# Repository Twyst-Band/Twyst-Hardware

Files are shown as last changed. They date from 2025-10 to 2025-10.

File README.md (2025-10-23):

# Twyst — Intelligent Motion Tracking & Exercise Feedback System

## Overview

Twyst is a wearable motion analysis system that integrates sensor-embedded bandanas with an intuitive mobile application to monitor, evaluate, and improve human movement. Designed for sports, fitness, rehabilitation, and physical therapy, Twyst provides real-time feedback on exercise execution accuracy using advanced motion analysis and AI-based comparison algorithms.

Developed by students from the National College of Computer Science “Grigore Moisil” Brașov, Twyst combines embedded engineering, data science, and mobile app design to create a seamless hardware-software ecosystem that makes motion tracking accessible and engaging.
 
## Objectives

Twyst aims to:
- Provide precise motion analysis using distributed wearable sensors.
- Deliver live, data-driven feedback for form correction and performance improvement.
- Develop a machine-learning framework that learns from professionals and guides beginners.
- Support medical rehabilitation by tracking therapeutic exercises and preventing re-injury.
- Offer a comfortable, modular, and scalable hardware system adaptable to various body types and activities.

Key operational goals include:
- <2° RMS error in orientation estimation.
- 95% exercise recognition accuracy.
- Real-time posture correction feedback.
- 8+ hours battery life and automatic calibration.

## How It Works

The system operates in two main phases:
1.	Training Phase – A professional user performs multiple repetitions of an exercise wearing several Twyst bandanas. The algorithm identifies the most relevant sensors and stores their motion data as a reference.
2.	User Phase – A beginner attaches bandanas to the same body parts and performs the exercise. Twyst compares their movement to the reference model, scoring accuracy and providing corrective suggestions.

Twyst uses sensor fusion (Kalman filters) to combine gyroscope, accelerometer, and magnetometer data. Movement analysis and comparison are based on Principal Component Analysis (PCA) for segmentation and Bézier curve modeling for motion representation, ensuring precise yet efficient feedback.

## Related Work

Twyst draws inspiration from several existing systems:
- SlimeVR: Open-source IMU-based full-body tracker for VR; lacks exercise integration and suffers from drift.
- OptiTrack: High-precision optical tracking used in professional environments; too costly and complex for personal use.
- Oculus Insight: Inside-out tracking with 6DoF accuracy; limited to upper-body movement and headset constraints.

Twyst bridges the gap — delivering OptiTrack-like accuracy with SlimeVR’s affordability and Oculus’ simplicity, optimized for fitness and rehabilitation.

## Software Architecture

Mobile Application
- Built in SwiftUI (iOS), with an Android version in development.
- Features include:
- Exercise browsing and categorization.
- Live activity tracking and performance analytics.
- Gamified UI inspired by Duolingo, featuring progress visualization, rewards, and motivational feedback.
- Mascot: Twy — a friendly athletic fox serving as a motivational guide and branding symbol.

Embedded Software
- Runs on ESP32-C3 using the Arduino framework (C).
- Handles sensor communication (SPI/I²C), data fusion, calibration, and Bluetooth data transfer.
- Implements local Kalman filtering before aggregating data to the main bandana and mobile app for analysis.

## Hardware Design

Bandana Types
- Main Bandana: Acts as the master node; equipped with a touchscreen, pulse oximeter, and temperature sensor.
- Secondary Bandanas: Smaller, lightweight, and communicate with the main unit via UWB and Bluetooth.

## Components

Component	Model / Description
Microcontroller	ESP32-C3
IMU	MPU9250
UWB Module	Ai-Thinker BU03 DW3000
Display	Waveshare Round TFT (GC9A01 driver)
Pulse Oximeter	GY-MAX30100
Temperature Sensor	MF52
Battery	Li-Po with Boost Regulator HW626
Material	PETG 3D-printed enclosures, nylon straps

## Electronics & Prototyping
- Designed using KiCad for PCB schematics.
- 3D-printed casings optimized for comfort and modular assembly.
- Built for durability, skin safety, and easy debugging.

## Business Model

Twyst’s business strategy focuses on:
- Selling hardware kits (bandanas + mobile app).
- Generating secondary revenue from anonymized motion data used in research, medicine, and biomechanics.
- Promoting accessibility and personalization to encourage wide adoption across fitness, rehabilitation, and research markets.

Business Plan
Research Paper

## Research & Algorithms

Twyst’s research focuses on mathematical modeling for accurate motion comparison:
- Sensor Model: Quaternion-based orientation estimation via Kalman filtering.
- Segmentation: PCA identifies repetitions and removes noise.
- Motion Representation: Bézier curves smooth motion data for scalable comparison.
- Evaluation Metrics: Curve distance, amplitude, and phase alignment define feedback precision.

These techniques ensure low drift, real-time responsiveness, and robust cross-user comparison.

## License

This project is currently in research and prototype stage under educational use. Future licensing will be determined upon commercial release.
 presentation)?

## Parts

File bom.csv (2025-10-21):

Designator | Footprint | Quantity | Value | LCSC Part #
C1, C2, C3 | C_0402 | 3 | 10µF
D1, D2 | 0402 | 2 | LED
D3 | Nexperia_CFP3_SOD-123W | 1 | PMEG4020ER
J1 | JST_PH_S2B-PH-K_1x02_P2.00mm_Horizontal | 1 | Conn_01x02_Pin
Q1 | SOT-23 | 1 | BSS84
R1 | R_0402 | 1 | 5.1kΩ
R2 | R_0402 | 1 | 2kΩ
R3, R4 | R_0402 | 2 | 1kΩ
R5 | R_0402 | 1 | 100kΩ
R6, R7 | R_0402 | 2 | 4.7kΩ
SW1 | SW_SPDT_PCM12 | 1 | SW_SPDT
U1 | TDFN-8_L3.0-W2.0-P0.50-BL-EP1.6 | 1 | MCP73831-2ACI/MC | C150772
U2 | SOT-23-5_L2.9-W1.6-P0.95-LS2.8-BR | 1 | AP2112K-3.3TRG1_C23380830 | C23380830
U4 | LGA-14_L3.0-W2.5-P0.50-TL | 1 | ICM-45686 | C22459454
U5 | WLCSP-12_L1.6-W1.6_BMM150 | 1 | BMM150 | C171681
U6 | MODULE_ESP32-C3_SUPERMINI_TH | 1 | ESP32-C3_SUPERMINI_TH
USBC1 | USB-C_SMD-TYPE-C-31-M-12_1 | 1 | TYPE-C-31-M-12 | C165948
`

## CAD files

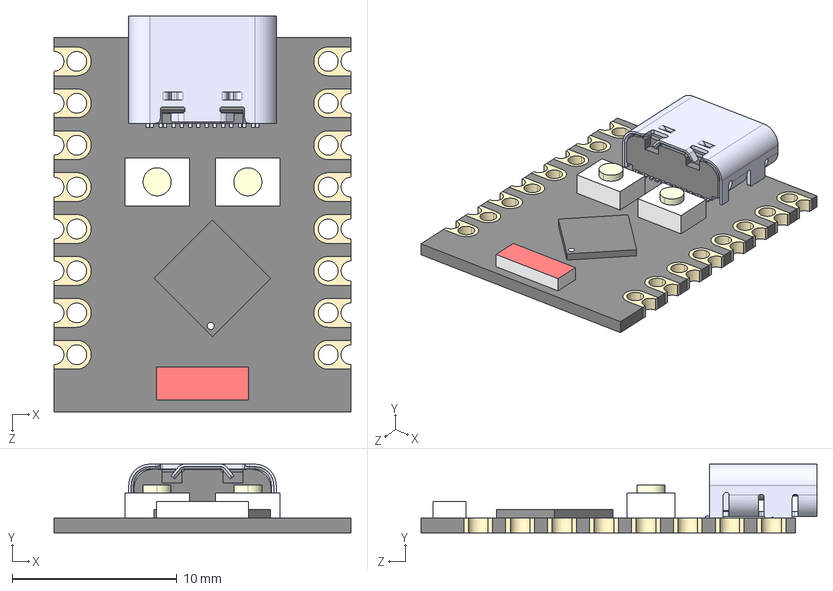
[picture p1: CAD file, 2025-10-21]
Electrical/ESP32-C3 SuperMini TH/ESP32-C3_SUPERMINI_TH.step
18.0 x 4.16 x 24.0 mm
Board c3mini
USB C
components (other)^ESP32-C3 SuperMini

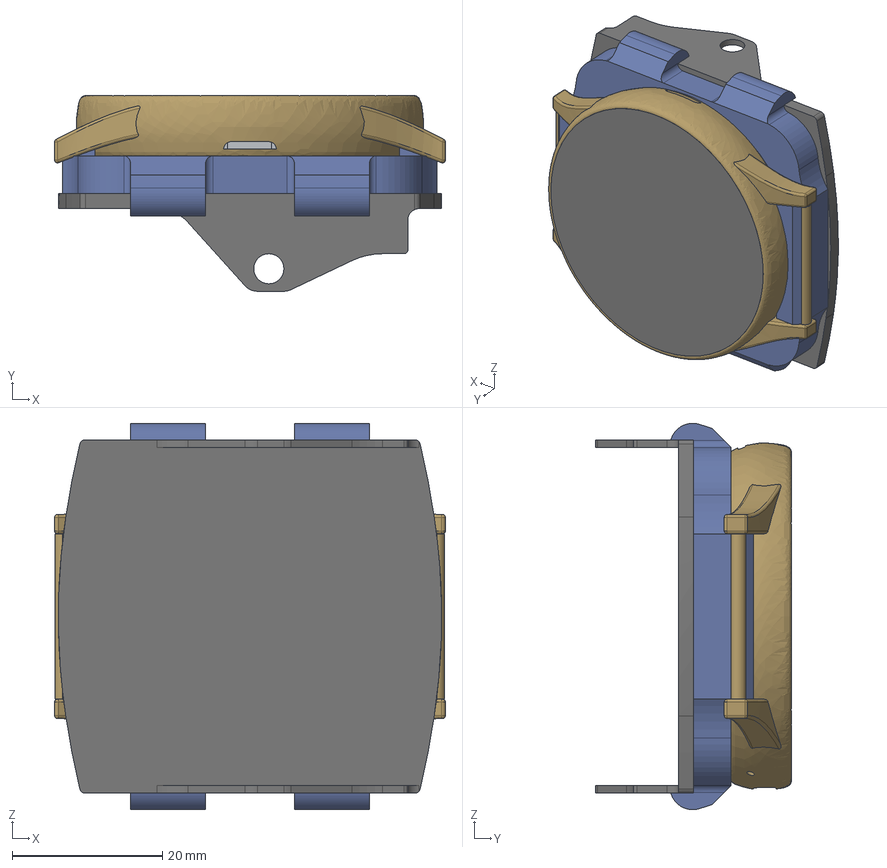
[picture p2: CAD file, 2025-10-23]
Models/Twyst v1 v4.step
52.0 x 26.0 x 51.4 mm
pcbBully
pcbBully2
pcbBully3
pcbBully4
MagnetBully1
PinBully2
SpeekerCase
MagnetBully2
PinBully1
Micro
SpeakerArcPlane
Motor
ClickButton
clock_1

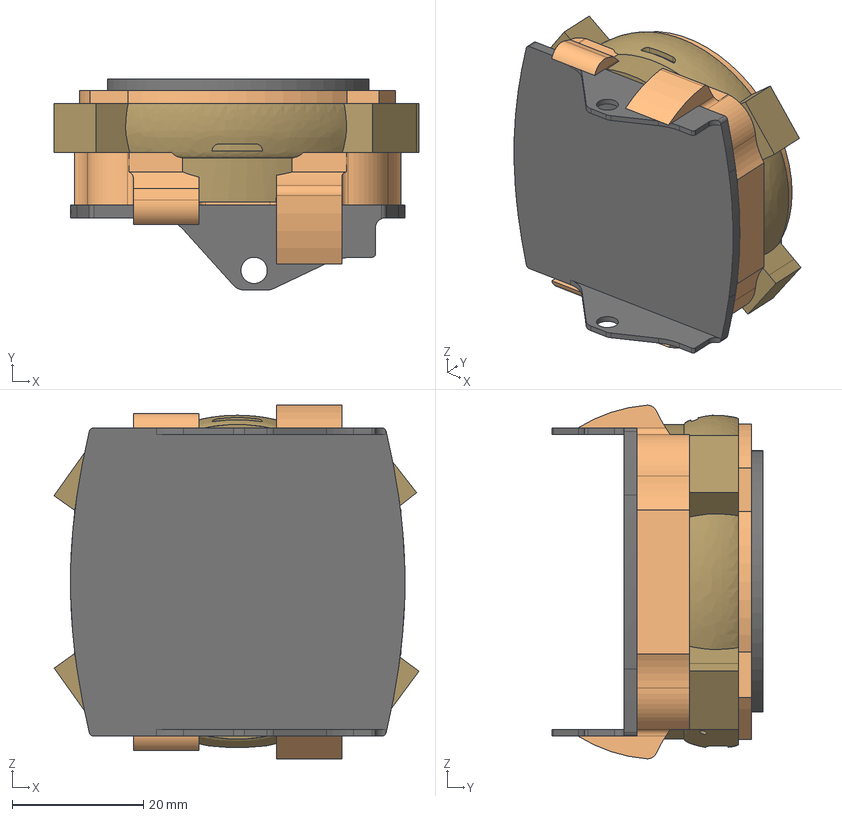
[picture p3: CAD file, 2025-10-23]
Models/Twyst v2 v1.step
55.6 x 32.2 x 53.9 mm
Arms
clock_1

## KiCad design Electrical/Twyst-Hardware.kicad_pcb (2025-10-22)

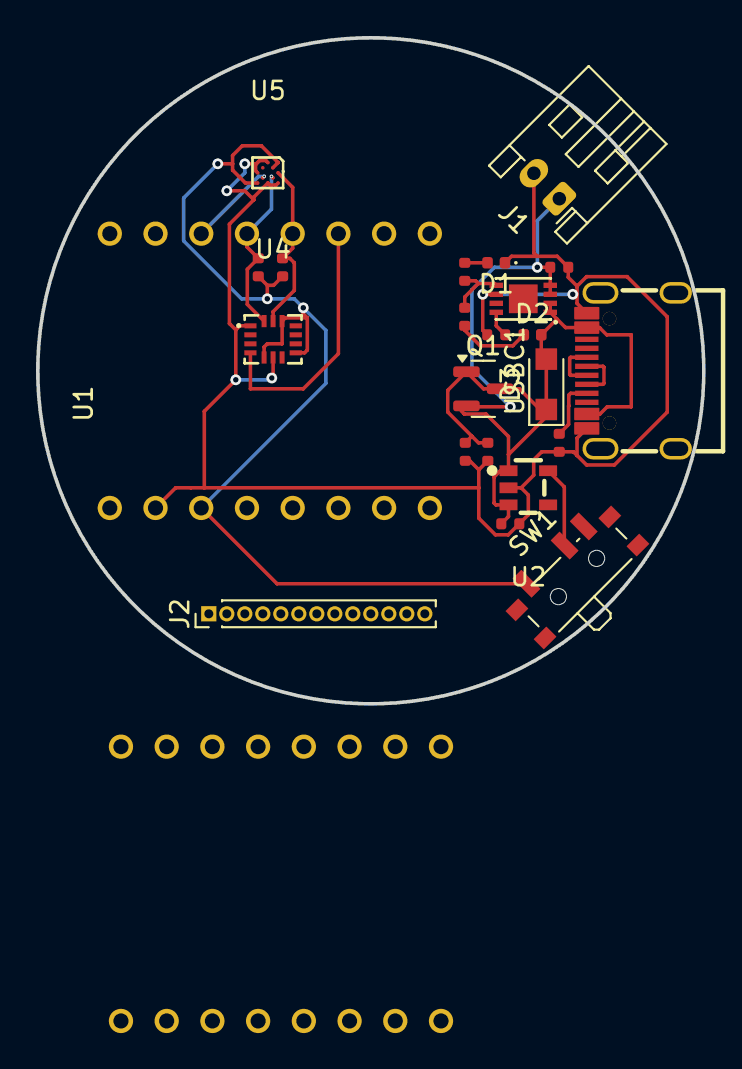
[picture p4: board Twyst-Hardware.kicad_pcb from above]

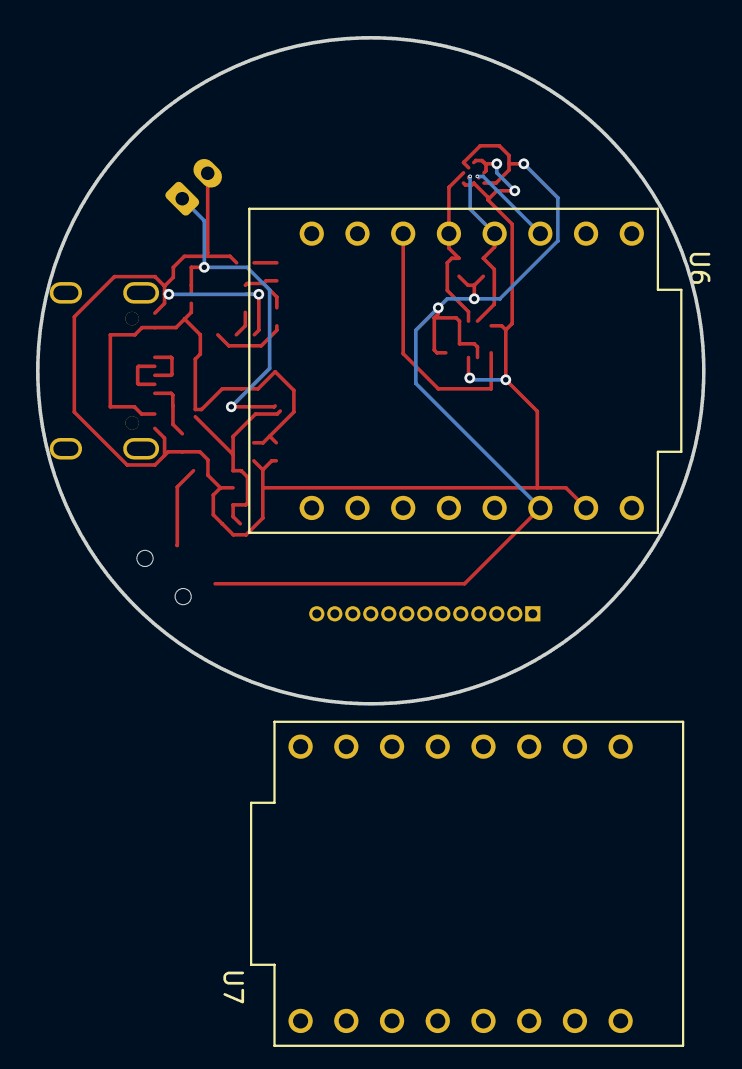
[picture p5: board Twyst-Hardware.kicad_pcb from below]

Board: 2 copper layers, 37.0 x 37.0 mm, 24 parts (2 on the bottom side), 17 nets.

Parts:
C1, C2, C3: 10µF; C_0402
D1, D2: LED; LED_0402_1005Metric
D3: PMEG4020ER; Nexperia_CFP3_SOD-123W
J1: Conn_01x02_Pin; JST_PH_S2B-PH-K_1x02_P2.00mm_Horizontal
J2: Conn_01x13_Pin; PinHeader_1x13_P1.00mm_Vertical
Q1: BSS84; SOT-23
R1: 5.1kΩ; R_0402
R2: 2kΩ; R_0402
R3, R4: 1kΩ; R_0402
R5: 100kΩ; R_0402
R6, R7: 4.7kΩ; R_0402
SW1: SW_SPDT; SW_SPDT_PCM12
U1: MCP73831-2ACI/MC; TDFN-8_L3.0-W2.0-P0.50-BL-EP1.6
U2: AP2112K-3.3TRG1_C23380830; SOT-23-5_L2.9-W1.6-P0.95-LS2.8-BR
U4: ICM-45686; LGA-14_L3.0-W2.5-P0.50-TL
U5: BMM150; WLCSP-12_L1.6-W1.6_BMM150
U6, U7: ESP32-C3_SUPERMINI_TH; MODULE_ESP32-C3_SUPERMINI_TH
USBC1: TYPE-C-31-M-12; USB-C_SMD-TYPE-C-31-M-12_1

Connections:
+3.3V: R6.1, R7.1, SW1.1 (A), U4.5 (VDDIO), U4.8 (VDD), U4.12 (AP_CS), U5.A1 (PS), U5.B2 (VDDIO), U5.E5 (VDD), U6.3.3 (3V3), U7.3.3 (3V3)
D+: USBC1.A7 (DN1), USBC1.B7 (DN2)
D-: USBC1.A6 (DP1), USBC1.B6 (DP2)
GND: C1.1, C2.2, C3.2, D1.1 (K), J1.2, R1.1, R2.2, R5.2, U1.6 (VSS), U2.2 (GND), U4.1 (AP_SDO/AP_AD0), U4.6 (GND), U5.A5 (CSB), U5.C1 (SDO), U5.C5 (GND), U5.E1 (GND), U5.E3 (GND), U6.G (GND), U7.G (GND), USBC1.A1B12 (GND), USBC1.B1A12 (GND)
unnamed: D1.2 (A), R4.1
unnamed: D2.1 (K), R3.1
unnamed: SW1.2 (B), U2.5 (VOUT)
unnamed: R2.1, U1.8 (PROG)
unnamed: R3.2, R4.2, U1.5 (STAT)
unnamed: R7.2, U4.13 (AP_SCL/AP_SCLK), U5.A3 (SCK), U6.9 (GPIO9)
unnamed: R6.2, U4.14 (AP_SDA/AP_SDIO/AP_SDI), U5.B4 (SDI), U6.8 (GPIO8)
unnamed: U4.4 (INT1/INT), U6.10 (GPIO10)
unnamed: U5.D4 (DRY), U6.7 (GPIO7)
unnamed: R1.2, USBC1.A5 (CC1)
VBAT: C2.1, J1.1, Q1.3 (D), U1.3 (VBAT), U1.4 (VBAT)
VBUS: C1.2, D2.2 (A), D3.2 (A), Q1.1 (G), R5.1, U1.1 (VDD), U1.2 (VDD), USBC1.A4B9 (VBUS), USBC1.B4A9 (VBUS)
VSH: C3.1, D3.1 (K), Q1.2 (S), U2.1 (VIN), U2.3 (EN)

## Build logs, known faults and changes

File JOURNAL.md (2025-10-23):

<!--
  ===================    !!READ THIS NOTICE!!   ====================
  DO NOT edit this file manually. Your changes WILL BE OVERWRITTEN!
  This journal is auto generated and updated by Hack Club Blueprint.
  To edit this file, please edit your journal entries on Blueprint.
  ==================================================================
-->

## 10/21/2025 - Created schematics and footprint for Twyst  

I just found out about the Blueprint program and since I've been working for a while on a new project, I thought I could add it here. This is the reason I've added so many hours at once, because I just discovered this program.
This is also my second and my most complicated hardware PCB project ever, so I am open to suggestions and tips on how to improve my device :))

My project consists of a set of wearable devices that contain an ESP32 C3 super mini, a charging module with LIPO batteries, an IMU module with gyroscope and accelerometer (ICM-45686) and a magnetometer (BMM150). All of these modules together are able to detect the moves and pose of the human body. While drifting is a concern, in most similar systems, my algorithm only requires absolute rotations of the bandanas for them to detect if the movements are correct. This will be done using a Kalman filter.

All work was initially done within EasyEDA, later being migrated to KiCad. I only used parts from LCSC so I can order from JLCPCB.

Below, you can see the schematic, footprint and 3D models of the PCB.



trese copy.png





## 10/22/2025 - Added round Screen Display to the default module  

My bandana system will be made out of 2 types of bandana, a main bandana and a secondary bandana. While the secondary only contains the schematics already added to this project, the main bandana also contains a few more modules, including a screen, a pulsoximeter and some other components. Today I added the screen.



## 10/23/2025 - Added final 3D models  

For today's journal, I made the final 2 advancements in my hardware development process. First, I tripple checked and ran the design rules checker for the electrical schema and footprint in Kicad to make sure everything is wired up correctly. Second, I made the 3D models for the bandanas!!!

Here are some photos:







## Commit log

2025-10-09 Fixed schematic
    [dpit.kicad_pcb, dpit.kicad_sch]
2025-10-21 Added new and improved schematic
    [dpit.kicad_pcb, dpit.kicad_sch]
2025-10-21 Added new and improved version
    [ESP32-C3_SUPERMINI_TH.step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]
2025-10-22 Refactored folder structure
    [ESP32-C3_SUPERMINI_TH.step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]
2025-10-22 Added screen module in schematics
    [Twyst-Hardware.kicad_pcb, Twyst-Hardware.kicad_sch]
2025-10-23 Added 3d models
    [Twyst v1 v4.step, Twyst v2 v1.step]
2025-10-23 Added necessary files for blueprint
    [bom.csv]
